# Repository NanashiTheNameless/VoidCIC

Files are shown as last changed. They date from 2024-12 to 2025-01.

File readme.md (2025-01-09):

# VoidCIC

## VoidCIC is a fork of the original [NullCIC](<https://github.com/Redherring32/NullCIC/>)

A little board to replace the CIC on the Original NES or [OpenTendo](<https://github.com/Redherring32/OpenTendo>), and restore reset functionality.

All the files needed to make your own are located in the [Production folder](<production>).

It is also for sale on my [Tindie](<https://www.tindie.com/products/37068/>) for those who dont wanna make it themselves, or those who want to support me!



You can also do the same thing that NullCIC/VoidCIC does manually, just check ["Reset fix without NullCIC(VoidCIC).jpg"](<Reset fix without NullCIC(VoidCIC).jpg>) for instructions!

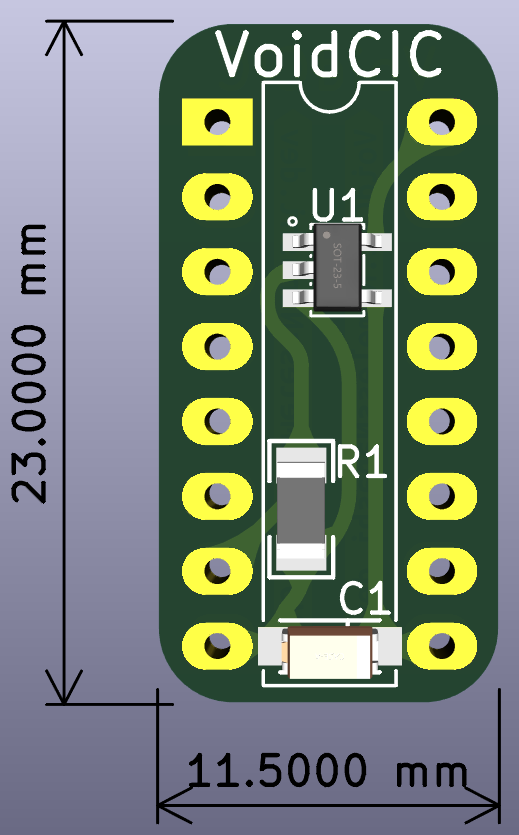
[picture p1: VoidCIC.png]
VoidCIC


## Credits

Original by [Redherring32](<https://github.com/Redherring32>), they did most (if not all) if the theoretical design and hard work!

VoidCIC is a fork of by [NullCIC](<https://github.com/Redherring32/NullCIC/>) made and maintaned by [NanashiTheNameless/NamelessNanashi](<https://NamelessNanashi.dev/>).

All of the [git contributors](<https://github.com/NanashiTheNameless/VoidCIC/graphs/contributors>).

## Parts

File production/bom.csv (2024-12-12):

Designator | Footprint | Quantity | Value | LCSC Part #
C1 | CAP-SMD_L3.2-W1.6-RD | 1 | TAJA474K035RNJ | C11368
R1 | R1206 | 1 | 1206W4F1002T5E | C17902
U1 | SOT-23-5_L3.0-W1.7-P0.95-LS2.8-BR | 1 | SN74LVC1GU04DBVR | C81934

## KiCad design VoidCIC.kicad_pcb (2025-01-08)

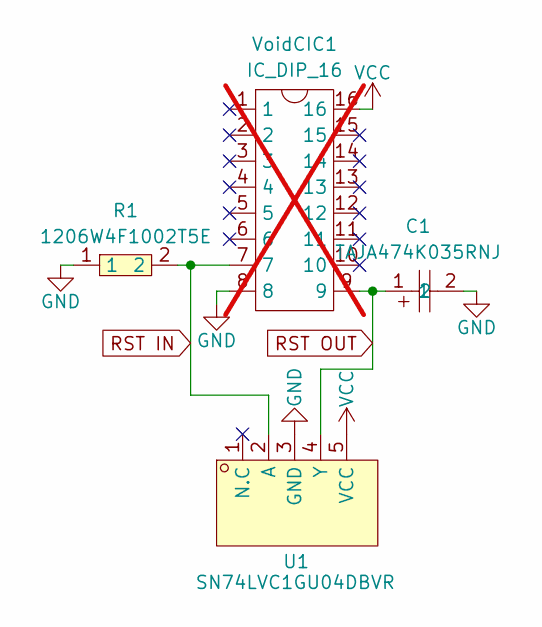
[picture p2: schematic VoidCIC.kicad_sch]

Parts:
C1: TAJA474K035RNJ; CAP-SMD_L3.2-W1.6-RD; LCSC Part C11368
R1: 1206W4F1002T5E; R1206; LCSC Part C17902
U1: SN74LVC1GU04DBVR; SOT-23-5_L3.0-W1.7-P0.95-LS2.8-BR; LCSC Part C81934
VoidCIC1: IC_DIP_16; DIP-16_W7.62mm_LongPads; not fitted

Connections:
GND: C1.2, R1.1, U1.3 (GND), VoidCIC1.8
RST IN: R1.2, U1.2 (A), VoidCIC1.7
RST OUT: C1.1, U1.4 (Y), VoidCIC1.9
VCC: U1.5 (VCC), VoidCIC1.16

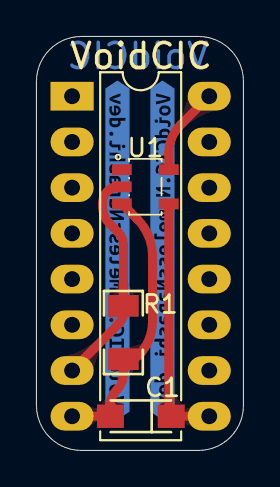
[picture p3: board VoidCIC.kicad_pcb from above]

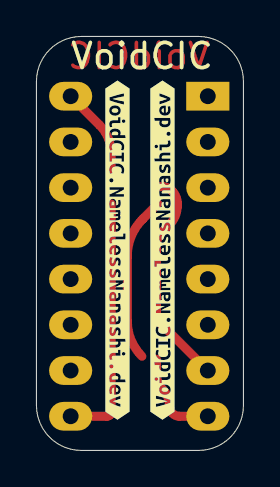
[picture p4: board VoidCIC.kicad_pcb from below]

Board: 2 copper layers, 11.5 x 23.0 mm, 8 parts (4 on the bottom side), 4 nets.

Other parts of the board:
kibuzzard-675A635B, kibuzzard-675A635B#2: G***; kibuzzard-675A635B
kibuzzard-675A6399, kibuzzard-675A6399#2: G***; kibuzzard-675A6399

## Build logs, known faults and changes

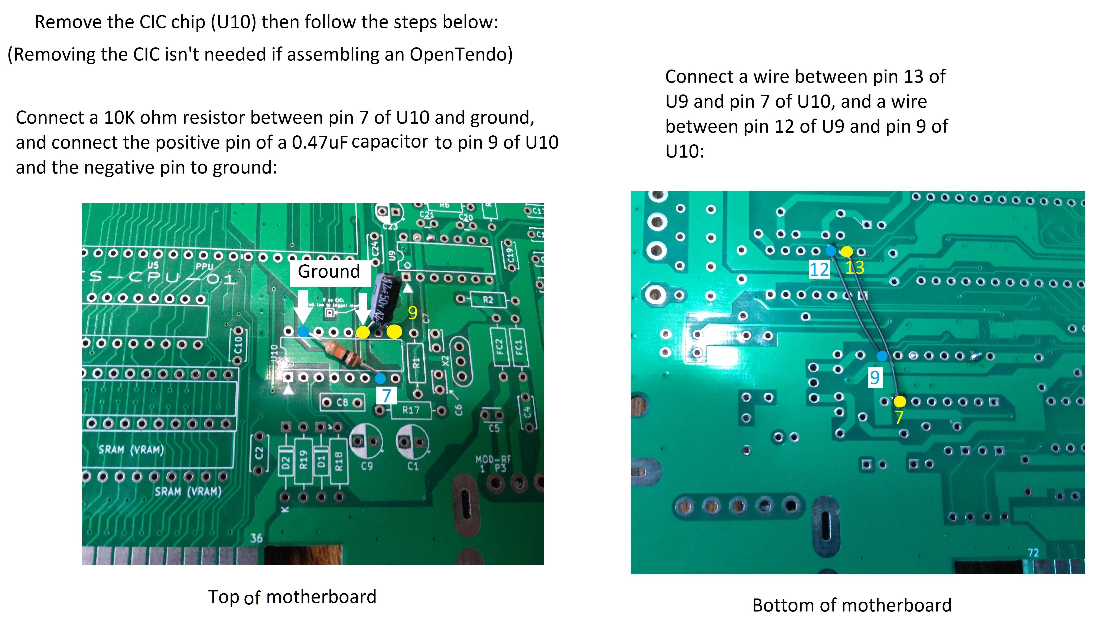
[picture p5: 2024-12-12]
Reset fix without NullCIC(VoidCIC).jpg

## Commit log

2024-12-12 Make initial overhaul
    [NullCIC.kicad_pcb, NullCIC.sch, VoidCIC.kicad_pcb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]
2024-12-12 Fix a silkscreen DFM error
    [VoidCIC.kicad_pcb]
2024-12-12 update production files
    [VoidCIC.kicad_pcb, bom.csv]
2024-12-12 update production files again
    [VoidCIC.kicad_pcb, VoidCIC.kicad_sch]
2024-12-12 update kicad model and add blender render
    [VoidCIC.kicad_pcb]
2024-12-12 Round tracks.
    [VoidCIC.kicad_pcb]
2024-12-13 MAJOR FIX: Repair Schematic to actually be correct now, Redherring32's schematic was a nightmare so I double checked the board and noticed this issue.
    [VoidCIC.kicad_pcb, VoidCIC.kicad_sch, positions.csv]
2024-12-14 update pcb and sch locations
    [VoidCIC.kicad_pcb, VoidCIC.kicad_sch]
2024-12-15 update production files to make soldering to easier
    [VoidCIC.kicad_pcb, positions.csv]
2025-01-08 update files to fix overly tight pin fit, its functional without but better this way
    [VoidCIC.kicad_pcb]
2025-01-08 Increase hole size more and round board to make the fixed version more apparent and hopefully make it look better
    [VoidCIC.kicad_pcb]
2025-06-03 update to kicad 9
